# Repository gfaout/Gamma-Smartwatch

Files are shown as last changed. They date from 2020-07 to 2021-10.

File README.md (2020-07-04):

# Gamma-Smartwatch
Smartwatch designed in Summer of 2020

Version A (basic version):

Top Board Unfilled:

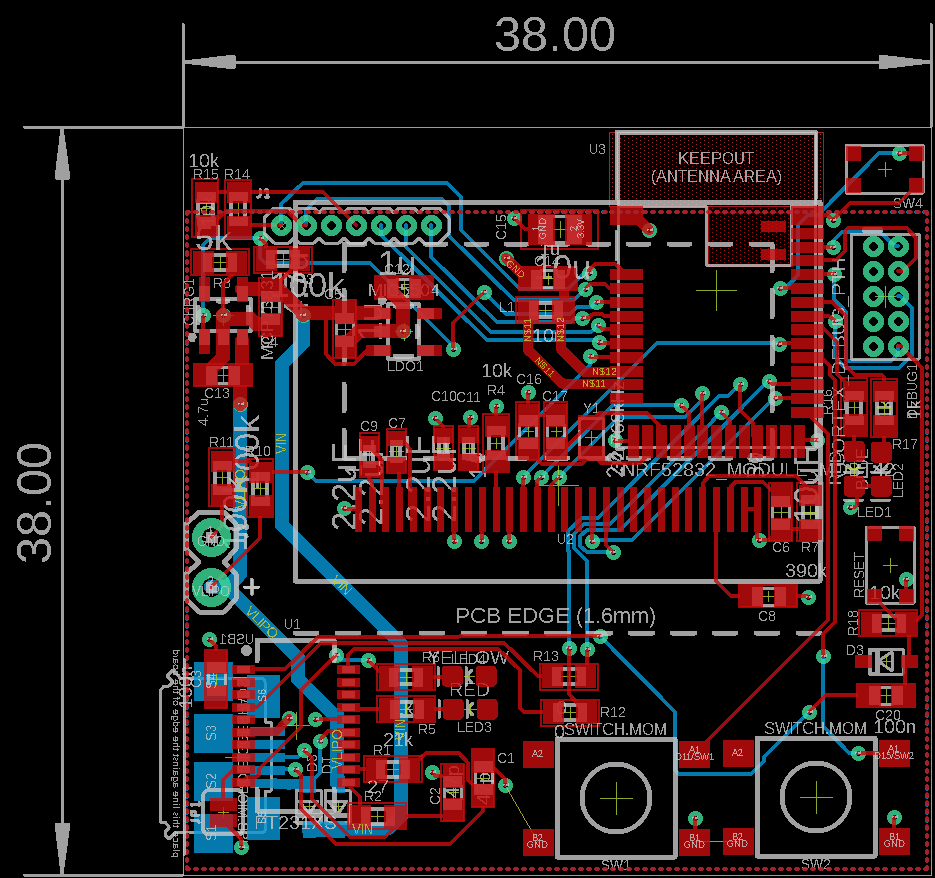
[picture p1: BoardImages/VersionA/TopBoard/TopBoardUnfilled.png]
The current unfilled top board


Top Board Filled:
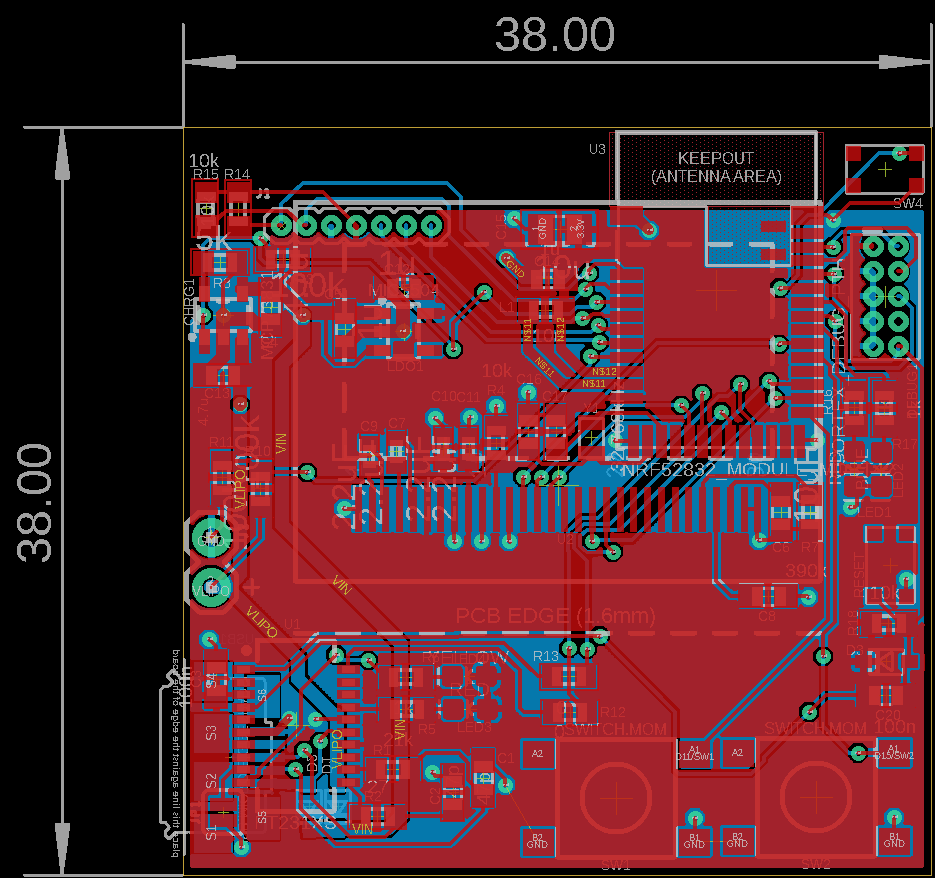
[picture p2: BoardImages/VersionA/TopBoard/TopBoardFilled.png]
The current filled top board


Bottom Board Unfilled:
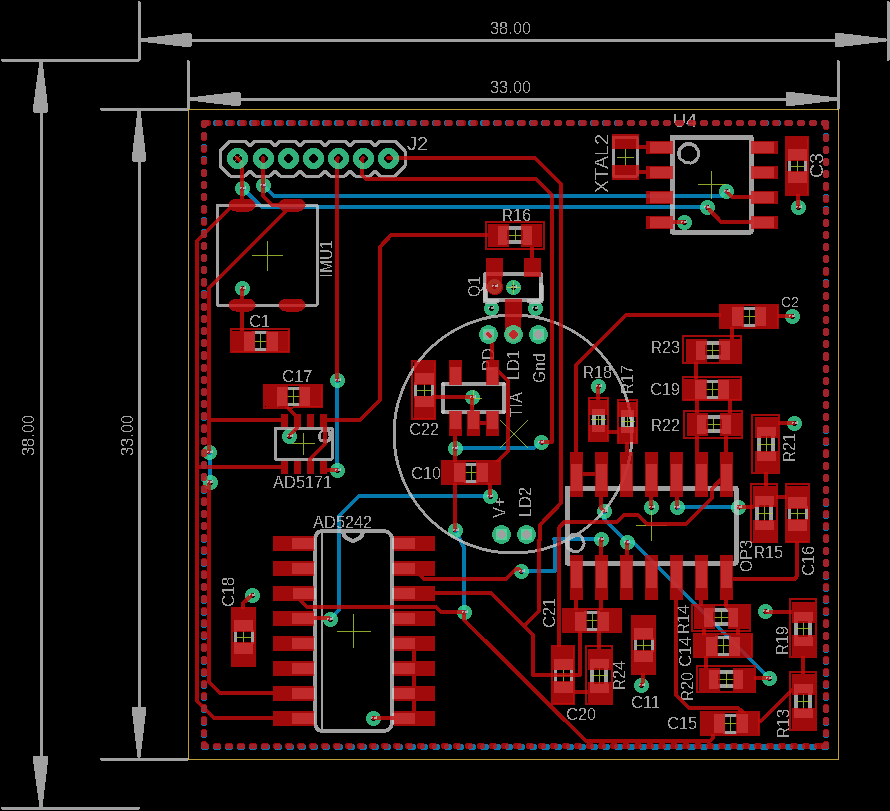
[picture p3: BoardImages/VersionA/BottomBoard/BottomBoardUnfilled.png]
The current unfilled bottom board


Bottom Board Filled:
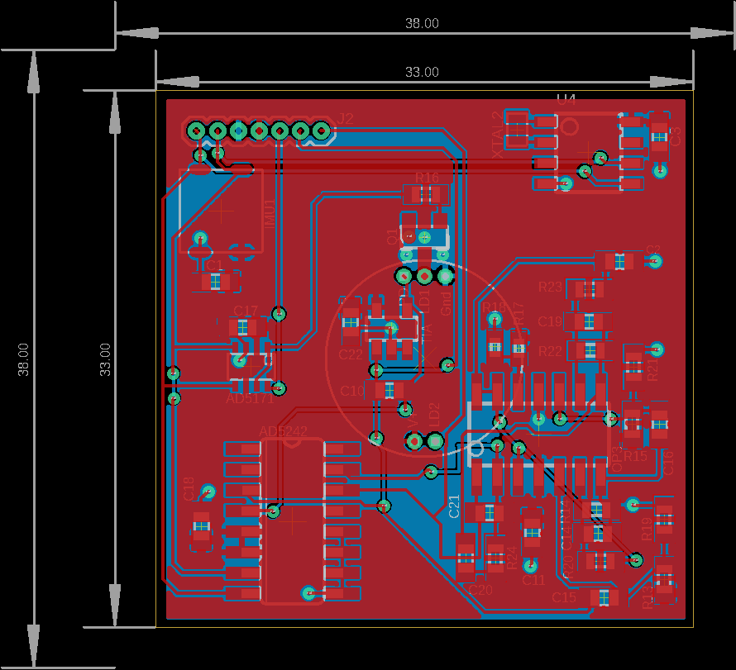
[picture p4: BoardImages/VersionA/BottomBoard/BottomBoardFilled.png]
The current filled bottom board


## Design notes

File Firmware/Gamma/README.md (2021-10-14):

This file is to lay out the general organization and initial testing of the Gamma Smartwatch firmware.

As of now, preliminary testing has been done on LCD displays, and i2c.  

Once parts are assembled (this will be done in the future), the full software testing and development will be completed.  

This is anticipated for Winter of 2022 and Spring of 2022 at the earliest.

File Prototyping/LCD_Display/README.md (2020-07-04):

# LCD Display (with Infrared Remote Control)

The code found in this folder was originally designed as my final project for the Arduino Milestone course.  
The link to the demonstration can be found [here](https://drive.google.com/file/d/1iYifw_N6cBzFy7ehYIgN_gkr_hAF68pH/view?usp=sharing)

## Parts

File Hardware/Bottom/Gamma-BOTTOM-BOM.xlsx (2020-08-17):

Gamma Smartwatch Bottom Board -- Revision A / Gautam Fotedar |  |  |  |  |  |  |  |  |  |  | Total | $0.00 | Total (in Bulk) | $0.00
BOM # | Comment | Designator | Description | Mounting Type | Package | Manufacturer | Manufacturer Part Number | Supplier | Supplier Part Number | Price per unit | Quantity | Total | Per 100 | Total
1 | CONN_07-1.27MM | J2 |  |  |  |  |  |  |  |  | 1 | $0.00 |  | $0.00
2 | LSM6DS3_CAST | IMU1 |  |  |  |  |  |  |  |  | 1 | $0.00 |  | $0.00
3 | 100 nF Capacitor | C1,C2,C10,C17,C18,C22 |  |  |  |  |  |  |  |  | 6 | $0.00 |  | $0.00
4 | 1 uF Capacitor | C3 |  |  |  |  |  |  |  |  | 1 | $0.00 |  | $0.00
5 | CRYSTALECS-.327-12.5-12-C-TR (CRYSTAL) (32.7680kHz) | XTAL2 |  |  |  |  |  |  |  |  | 1 | $0.00 |  | $0.00
6 | PCF8523 | U4 |  |  |  |  |  |  |  |  | 1 | $0.00 |  | $0.00
7 | 0.05 spaced Header Pins | J2 | Connector Header Through Hole 50 position 0.050" (1.27mm) |  |  | Sullins Connector Solutions | GRPB501VWVN-RC |  | S9014E-50-ND |  | 1 | $0.00 |  | $0.00
8 | AD5171 | AD5172 |  |  |  |  |  |  |  |  | 1 | $0.00 |  | $0.00
9 | AD5242 | AD5243 |  |  |  |  |  |  |  |  | 1 | $0.00 |  | $0.00
10 | TIA | TIA |  |  |  |  |  |  |  |  | 1 | $0.00 |  | $0.00
11 | NPN-Generic | Q1 |  |  |  |  |  |  |  |  | 1 | $0.00 |  | $0.00
12 | Resistor (valueless) | R16 |  |  |  |  |  |  |  |  | 1 | $0.00 |  | $0.00
13 | 1M Resistor | R20,R23 |  |  |  |  |  |  |  |  | 2 | $0.00 |  | $0.00
14 | 2.2n Capacitor | C14,C19 |  |  |  |  |  |  |  |  | 2 | $0.00 |  | $0.00
15 | 10M Resistor | R14,R22 |  |  |  |  |  |  |  |  | 2 | $0.00 |  | $0.00
16 | 10k Resistor | R17,R18,R24 |  |  |  |  |  |  |  |  | 3 | $0.00 |  | $0.00
17 | 220k resistor | R13,R19,R21 |  |  |  |  |  |  |  |  | 3 | $0.00 |  | $0.00
18 | Op amp | OP3 |  |  |  |  |  |  |  |  | 1 | $0.00 |  | $0.00
19 | 22n capacitor | C21 |  |  |  |  |  |  |  |  | 1 | $0.00 |  | $0.00
20 | 22u capacitor | C20 |  |  |  |  |  |  |  |  | 1 | $0.00 |  | $0.00
21 | 2.2u capacitor | C15 |  |  |  |  |  |  |  |  | 1 | $0.00 |  | $0.00

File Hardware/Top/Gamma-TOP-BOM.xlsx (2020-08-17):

Gamma Smartwatch Top Board -- Revision A / Gautam Fotedar |  |  |  |  |  |  |  |  |  |  | Total | $0.00 | Total (in Bulk) | $0.00
BOM # | Comment | Designator | Description | Mounting Type | Package | Manufacturer | Manufacturer Part Number | Supplier | Supplier Part Number | Price per unit | Quantity | Total | Per 100 | Total
1 | 47 pF Capacitor | C1,C2 |  |  |  |  |  |  |  |  | 2 | $0.00 |  | $0.00
2 | 27 ohm resistor | R1,R2 |  |  |  |  |  |  |  |  | 2 | $0.00 |  | $0.00
3 | 100 nF Capacitor | C3, C19, C20 |  |  |  |  |  |  |  |  | 3 | $0.00 |  | $0.00
4 | FT231XS USB Serial | U1 |  |  |  |  |  |  |  |  | 1 | $0.00 |  | $0.00
5 | SMT-JUMPER_2_NO_SILK (Version 1) | JP1 |  |  |  |  |  |  |  |  | 1 | $0.00 |  | $0.00
6 | 1k Resistor | R5, R6, R16, R17 |  |  |  |  |  |  |  |  | 4 | $0.00 |  | $0.00
7 | Red LED | LED1, LED3 |  |  |  |  |  |  |  |  | 2 | $0.00 |  | $0.00
8 | Yellow LED | LED4 |  |  |  |  |  |  |  |  | 1 | $0.00 |  | $0.00
9 | 0 ohm resistor (not sure if needed) | R12, R13 |  |  |  |  |  |  |  |  | 2 | $0.00 |  | $0.00
10 | CONN_07-1.27MM (CONN_07) | J1 |  |  |  |  |  |  |  |  | 1 | $0.00 |  | $0.00
11 | OLED UG-2864HSWEG01 | U2 |  |  |  |  |  |  |  |  | 1 | $0.00 |  | $0.00
12 | 2.2 uF 0402 Capacitor | C7, C9, C10, C11 |  |  |  |  |  |  |  |  | 4 | $0.00 |  | $0.00
13 | 10k resistor | R4, R14, R15, R18 |  |  |  |  |  |  |  |  | 4 | $0.00 |  | $0.00
14 | 390k resistor | R7 |  |  |  |  |  |  |  |  | 1 | $0.00 |  | $0.00
15 | 2.2 uF 0603 Capacitor | C8 |  |  |  |  |  |  |  |  | 1 | $0.00 |  | $0.00
16 | 10 uF 0603 Capacitor | C6, C15 |  |  |  |  |  |  |  |  | 2 | $0.00 |  | $0.00
17 | CONN_02 for Power Management | J2 |  |  |  |  |  |  |  |  | 1 | $0.00 |  | $0.00
18 | Schottky Diode | D1,D2, D3 |  |  |  |  |  |  |  |  | 3 | $0.00 |  | $0.00
19 | 1 uF 0603 capacitor | C5,C12, C14 |  |  |  |  |  |  |  |  | 3 | $0.00 |  | $0.00
20 | MIC5504 Voltage Regulator | LDO1 |  |  |  |  |  |  |  |  | 1 | $0.00 |  | $0.00
21 | 4.7 uF Capacitor | C4, C13 |  |  |  |  |  |  |  |  | 2 | $0.00 |  | $0.00
22 | 100K Resistor | R3, R10, R11 |  |  |  |  |  |  |  |  | 3 | $0.00 |  | $0.00
23 | MCP73831 T Li-Ion, Li-Pol Controller | CHRG1 |  |  |  |  |  |  |  |  | 1 | $0.00 |  | $0.00
24 | 5k resistor | R8 |  |  |  |  |  |  |  |  | 1 | $0.00 |  | $0.00
25 | FT24C64A EEPROM | U5 |  |  |  |  |  |  |  |  | 1 | $0.00 |  | $0.00
26 | 120 pF Capacitor | C18, C21 |  |  |  |  |  |  |  |  | 2 | $0.00 |  | $0.00
27 | 2.1 uH NFC Antenna | NFCANTENNA |  |  |  | Molex | 1462360151 |  |  |  | 1 | $0.00 |  | $0.00
28 | SPST-PTS830GG140 | RESET |  |  |  |  |  |  |  |  | 1 | $0.00 |  | $0.00
29 | Cortex Debug Connector - 10 pin | DEBUG1 |  |  |  |  |  |  |  |  | 1 | $0.00 |  | $0.00
30 | SWITCH.MOM (TACTILE_SWITCH_SMD_6.2MM_TALL) | SW1, SW2 |  |  |  |  |  |  |  |  | 2 | $0.00 |  | $0.00
31 | DFU SPST-PTS830GG140 | SW4 |  |  |  |  |  |  |  |  | 1 | $0.00 |  | $0.00
32 | 10 uH Inductor | L1 |  |  |  |  |  |  |  |  | 1 | $0.00 |  | $0.00
33 | Valuelesss capacitors | C16, C17 |  |  |  |  |  |  |  |  | 2 | $0.00 |  | $0.00
34 | CRYSTALECS-.327-12.5-12-C-TR (CRYSTAL) (32.768kHz) | Y1 |  |  |  |  |  |  |  |  | 1 | $0.00 |  | $0.00
35 | Blue LED | LED2 |  |  |  |  |  |  |  |  | 1 | $0.00 |  | $0.00
36 | NRF52832_MODULE_MDBT42 | U3 |  |  |  |  |  |  |  |  | 1 | $0.00 |  | $0.00

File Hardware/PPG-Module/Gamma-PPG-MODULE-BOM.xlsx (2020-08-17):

Design Name -- Revision Code / Designer |  |  |  |  |  |  |  |  |  |  | Total | $4.73 | Total (in Bulk) | $3.24
BOM # | Comment | Designator | Description | Mounting Type | Package | Manufacturer | Manufacturer Part Number | Supplier | Supplier Part Number | Price per unit | Quantity | Total | Per 100 | Total
1 | Photodiode | PD | Photodiode 940nm 100ns 130° 2-SMD, Gull Wing | SMD | 2-SMD, Gull Wing | Vishay Semiconductor Opto Division | VBPW34S | Digi-Key | 751-1500-1-ND | $1.13 | 1 | $1.13 | $0.57 | $0.57
2 | 2.2uF capacitor | C1 | 2.2µF ±10% 25V Ceramic Capacitor X5R 0603 (1608 Metric) | SMD | 0603 | Samsung Electro-Mechanics | CL10A105KA8NNNC | Digi-Key | 1276-1102-1-ND | $0.10 | 1 | $0.10 | $0.02 | $0.02
3 | Green LED | LED1 | Green 525nm LED Indication - Discrete 3.1V 0805 (2012 Metric) | SMD | 0805 | QT Brightek (QTB) | QBLP631-IG | Digi-Key | 1516-1084-1-ND | $0.39 | 1 | $0.39 | $0.16 | $0.16
4 | 0.05 spaced Header Pins | J1 | Connector Header Through Hole 50 position 0.050" (1.27mm) | THT | N/A | Sullins Connector Solutions | GRPB501VWVN-RC | Digi-Key | S9014E-50-ND | $3.11 | 1 | $3.11 | $2.49 | $2.49

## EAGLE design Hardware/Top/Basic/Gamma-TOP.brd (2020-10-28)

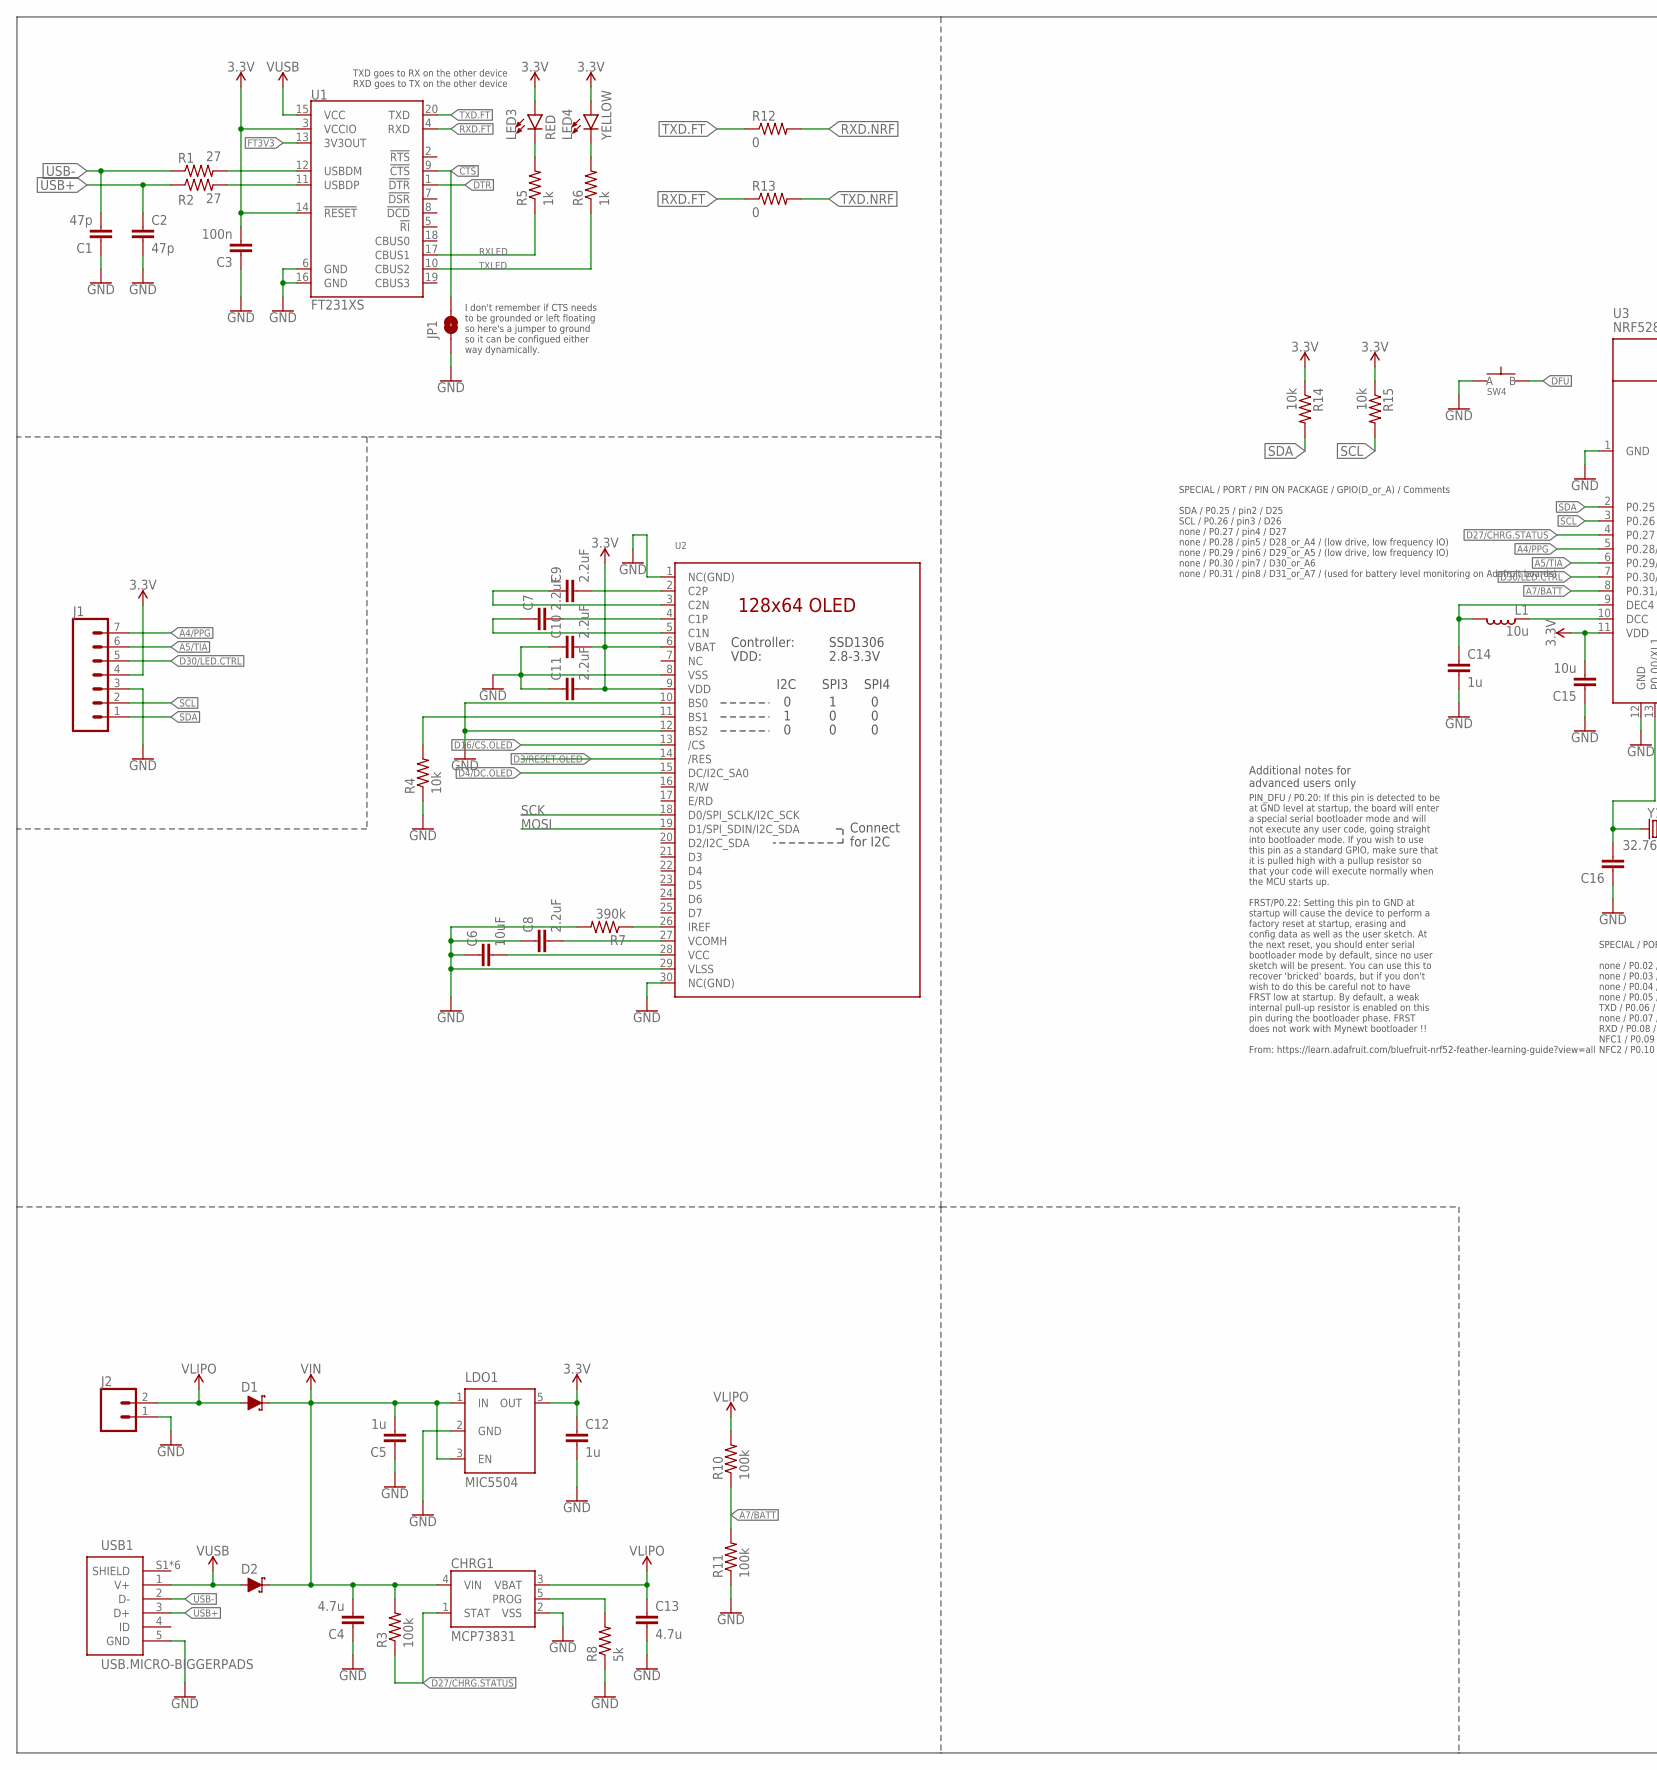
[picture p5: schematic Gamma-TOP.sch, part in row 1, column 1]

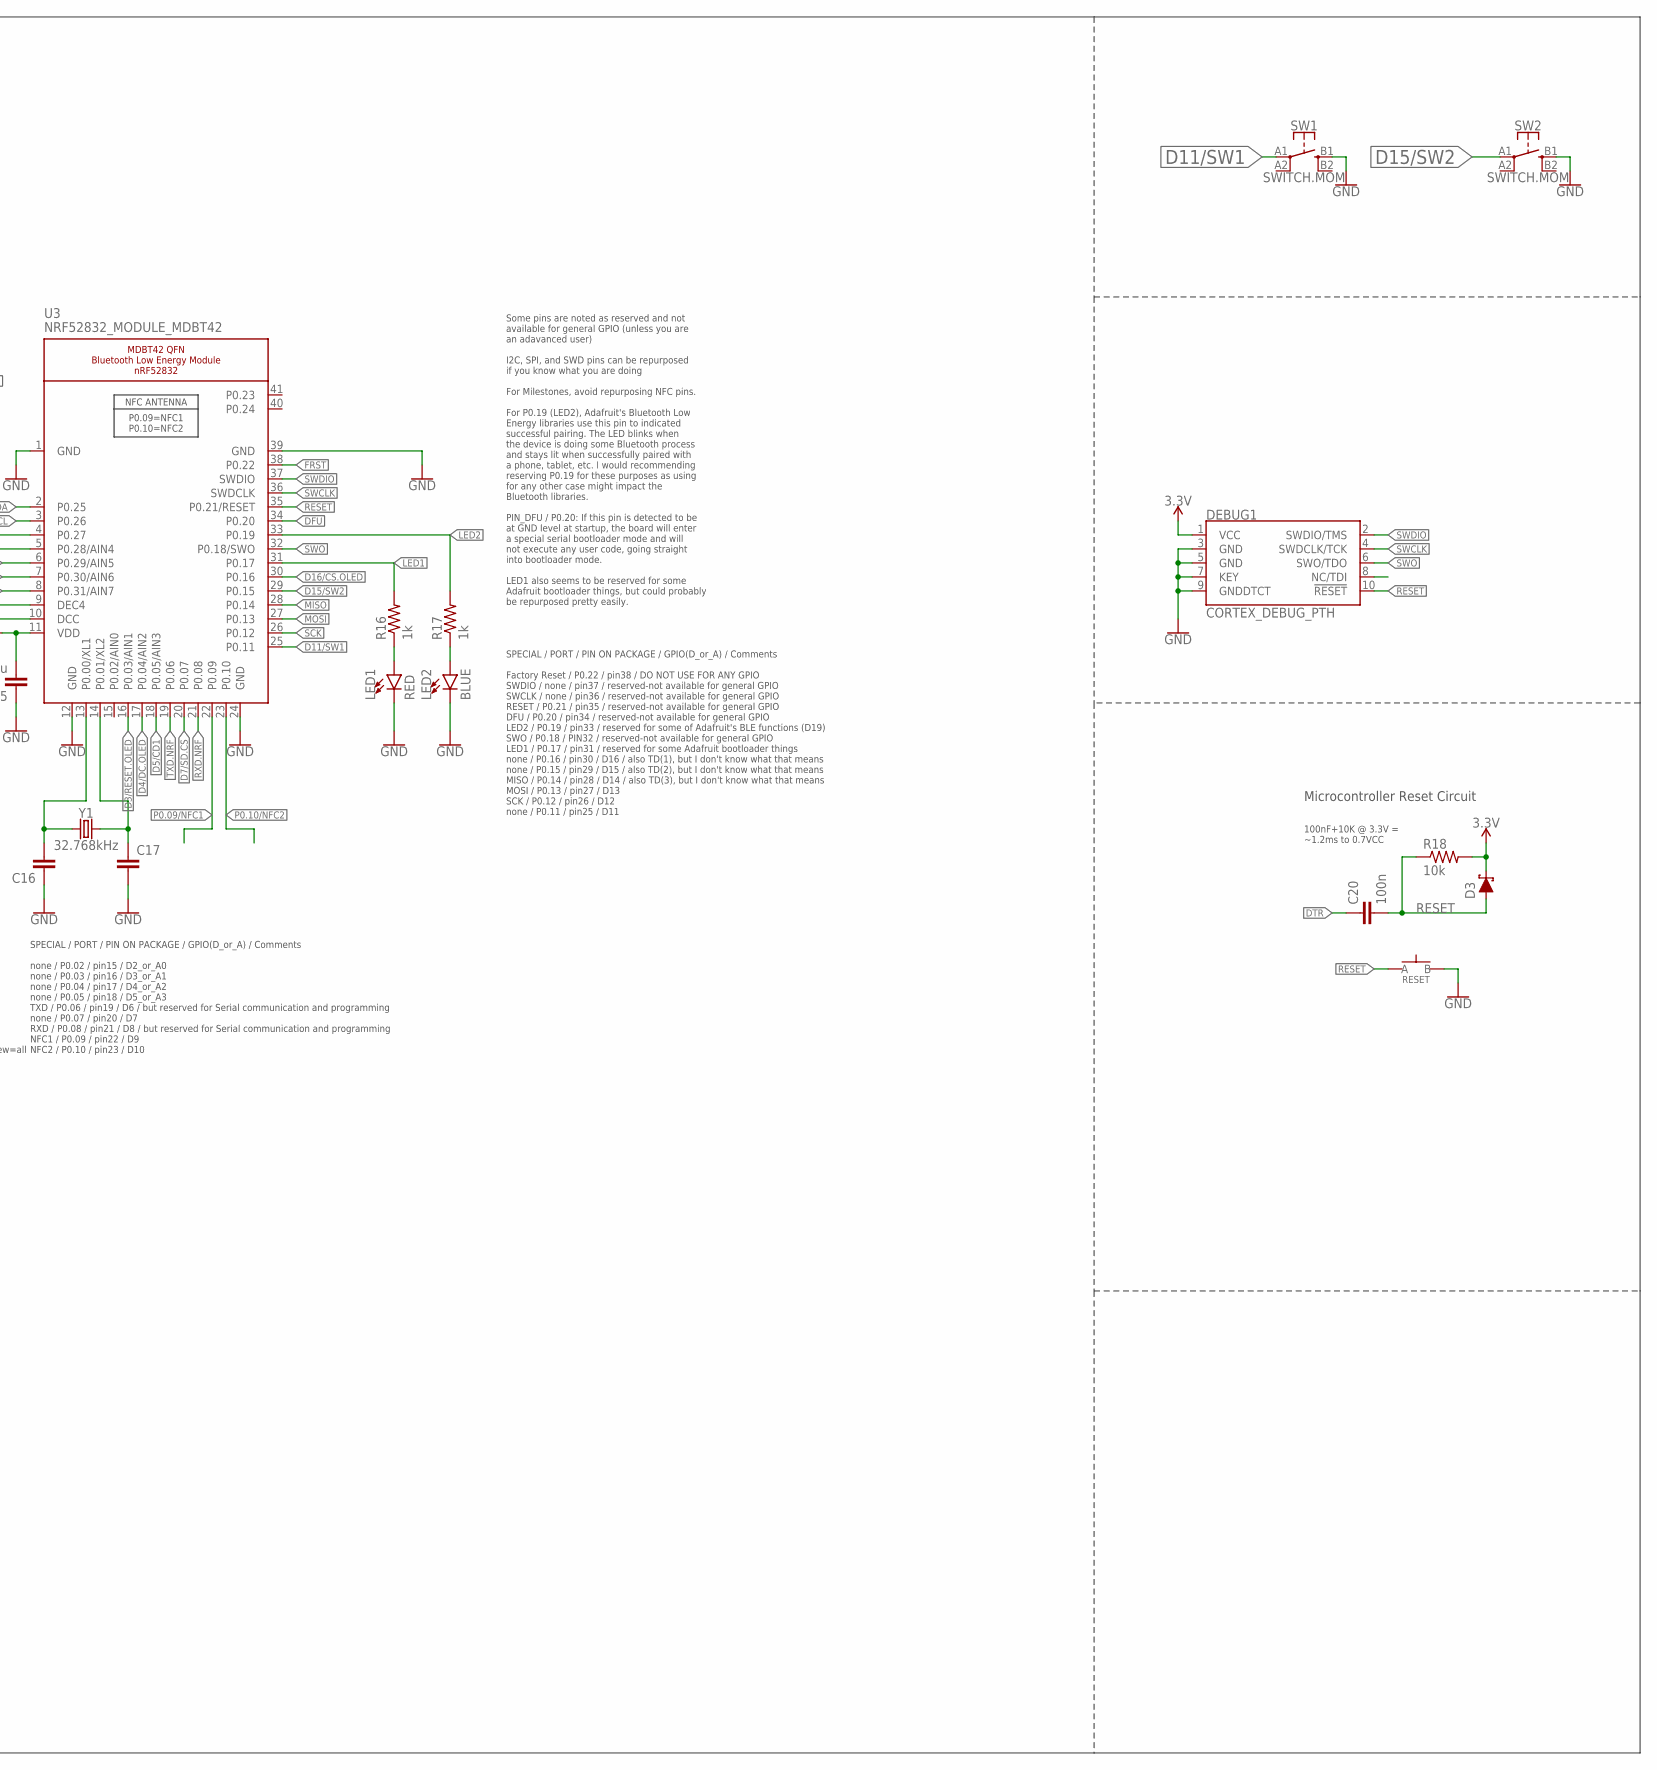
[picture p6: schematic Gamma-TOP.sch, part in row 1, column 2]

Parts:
C1, C2: 47p; C0603
C3, C20: 100n; C0603
C4, C13: 4.7u; C0603
C5, C12, C14: 1u; C0603
C6: 10uF; C0603
C7, C9, C10, C11: 2.2uF; C0402
C8: 2.2uF; C0603
C15: 10u; C0805
C16, C17: CAPACITOR0603; C0603
CHRG1: MCP73831; SOT23-5
D1, D2, D3: SCHOTTKY-USC; USC
DEBUG1: CORTEX_DEBUG_PTH; 2X5-PTH-1.27MM
J1: CONN_07-1.27MM; 1X07_1.27MM
J2: CONN_02; 1X02
JP1: JUMPER-SMT_2_NO_SILK; SMT-JUMPER_2_NO_SILK
L1: 10u; L0603
LDO1: MIC5504; SOT23-5
LED1, LED3: RED; LED-0603
LED2: BLUE; LED-0603
LED4: YELLOW; LED-0603
R1, R2: 27; R0603
R3, R10, R11: 100k; R0603
R4, R14, R15, R18: 10k; R0603
R5, R6, R16, R17: 1k; R0603
R7: 390k; R0603
R8: 5k; R0603
R12, R13: 0; R0603
RESET: SPST-PTS830GG140-COPY.1-3; BUTTON-GULLWING
SW1, SW2: SWITCH.MOM; TACTILE_SWITCH_SMD_6.2MM_TALL
SW4: SPST-PTS830GG140-COPY.1-3; BUTTON-GULLWING
U1: FT231XS; SSOP20_L
U2: DISP_OLED_UG-2864HSWEG01-NO-WRAPAROUND; UG-2864HSWEG01_0.96IN_NO-WRAPAROUND
U3: NRF52832_MODULE_MDBT42; BLE_MODULE_RAYTAC_MDBT42
USB1: USB.MICRO-BIGGERPADS; USB-MICRO-01.BIGGERPADS
Y1: 32.768kHz; 2-SMD.NOLEAD.2.0MMTO1.2MM

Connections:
3.3V: C3.2, C10.2, C11.2, C12.1, C15.2, D3.- (C), DEBUG1.1 (VCC), J1.4, LDO1.5 (OUT), LED3.A, LED4.A, R14.1, R15.1, R18.2, U1.3 (VCCIO), U1.14 (!RESET), U2.6 (VBAT), U2.9 (VDD), U3.11 (VDD)
!CTS: JP1.2, U1.9 (!CTS)
A4/PPG: J1.7, U3.5 (P0.28/AIN4)
A5/TIA: J1.6, U3.6 (P0.29/AIN5)
A7/BATT: R10.1, R11.2, U3.8 (P0.31/AIN7)
D3/RESET.OLED: U2.14 (/RES), U3.16 (P0.03/AIN1)
D4/DC.OLED: U2.15 (DC/I2C_SA0), U3.17 (P0.04/AIN2)
D5/CD1: U3.18 (P0.05/AIN3)
D7/SD.CS: U3.20 (P0.07)
D11/SW1: SW1.A1 (1), U3.25 (P0.11)
D15/SW2: SW2.A1 (1), U3.29 (P0.15)
D16/CS.OLED: U2.13 (/CS), U3.30 (P0.16)
D27/CHRG.STATUS: CHRG1.1 (STAT), R3.1, U3.4 (P0.27)
D30/LED.CTRL: J1.5, U3.7 (P0.30/AIN6)
DFU: SW4.3 (B), U3.34 (P0.20)
DTR: C20.1, U1.1 (!DTR)
FRST: U3.38 (P0.22)
FT3V3: U1.13 (3V3OUT)
GND: C1.1, C2.2, C3.1, C4.1, C5.1, C6.1, C8.1, C10.1, C11.1, C12.2, C13.2, C14.2, C15.1, C16.1, C17.2, CHRG1.2 (VSS), DEBUG1.3 (GND), DEBUG1.5 (GND), DEBUG1.7 (KEY), DEBUG1.9 (GNDDTCT), J1.3, J2.1, JP1.1, LDO1.2 (GND), LED1.C, LED2.C, R4.1, R7.2, R8.1, R11.1, RESET.3 (B), SW1.B1 (3), SW2.B1 (3), SW4.1 (A), U1.6 (GND), U1.16 (GND), U2.1 (NC(GND)), U2.8 (VSS), U2.10 (BS0), U2.12 (BS2), U2.29 (VLSS), U2.30 (NC(GND)), U3.1 (GND), U3.12 (GND), U3.24 (GND), U3.39 (GND), USB1.5 (GND)
LED1: R16.2, U3.31 (P0.17)
LED2: R17.2, U3.33 (P0.19)
MISO: U3.28 (P0.14)
MOSI: U2.19 (D1/SPI_SDIN/I2C_SDA), U3.27 (P0.13)
unnamed: R4.2, U2.11 (BS1)
unnamed: R7.1, U2.26 (IREF)
unnamed: C9.2, U2.2 (C2P)
unnamed: C16.2, U3.13 (P0.00/XL1), Y1.P$1 (1)
unnamed: C9.1, U2.3 (C2N)
unnamed: C17.1, U3.14 (P0.01/XL2), Y1.P$2 (2)
unnamed: C7.2, U2.4 (C1P)
unnamed: C7.1, U2.5 (C1N)
unnamed: LED1.A, R16.1
unnamed: LED2.A, R17.1
unnamed: L1.1, U3.10 (DCC)
unnamed: C14.1, L1.2, U3.9 (DEC4)
unnamed: C6.2, U2.28 (VCC)
unnamed: C8.2, U2.27 (VCOMH)
unnamed: CHRG1.5 (PROG), R8.2
unnamed: R1.2, U1.12 (USBDM)
unnamed: R2.2, U1.11 (USBDP)
unnamed: LED3.C, R5.2
unnamed: LED4.C, R6.2
P0.09/NFC1: U3.22 (P0.09)
P0.10/NFC2: U3.23 (P0.10)
RESET: C20.2, D3.+ (A), DEBUG1.10 (!RESET), R18.1, RESET.1 (A), U3.35 (P0.21/RESET)
RXD.FT: R13.1, U1.4 (RXD)
RXD.NRF: R12.2, U3.21 (P0.08)
RXLED: R5.1, U1.17 (CBUS1)
SCK: U2.18 (D0/SPI_SCLK/I2C_SCK), U3.26 (P0.12)
SCL: J1.2, R15.2, U3.3 (P0.26)
SDA: J1.1, R14.2, U3.2 (P0.25)
SWCLK: DEBUG1.4 (SWDCLK/TCK), U3.36 (SWDCLK)
SWDIO: DEBUG1.2 (SWDIO/TMS), U3.37 (SWDIO)
SWO: DEBUG1.6 (SWO/TDO), U3.32 (P0.18/SWO)
TXD.FT: R12.1, U1.20 (TXD)
TXD.NRF: R13.2, U3.19 (P0.06)
TXLED: R6.1, U1.10 (CBUS2)
USB+: C2.1, R2.1, USB1.3 (D+)
USB-: C1.2, R1.1, USB1.2 (D-)
VIN: C4.2, C5.2, CHRG1.4 (VIN), D1.- (C), D2.- (C), LDO1.1 (IN), LDO1.3 (EN), R3.2
VLIPO: C13.1, CHRG1.3 (VBAT), D1.+ (A), J2.2, R10.2
V_USB: D2.+ (A), U1.15 (VCC), USB1.1 (V+)

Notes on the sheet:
Microcontroller Reset Circuit
100nF+10K @ 3.3V = ~1.2ms to 0.7VCC
SPECIAL / PORT / PIN ON PACKAGE / GPIO(D_or_A) / Comments SDA / P0.25 / pin2 / D25 SCL / P0.26 / pin3 / D26 none / P0.27 / pin4 / D27 none / P0.28 / pin5 / D28_or_A4 / (low drive, low frequency IO) none / P0.29 / pin6 / D29_or_A5 / (low drive, low frequency IO) none / P0.30 / pin7 / D30_or_A6 none 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
SPECIAL / PORT / PIN ON PACKAGE / GPIO(D_or_A) / Comments none / P0.02 / pin15 / D2_or_A0 none / P0.03 / pin16 / D3_or_A1 none / P0.04 / pin17 / D4_or_A2 none / P0.05 / pin18 / D5_or_A3 TXD / P0.06 / pin19 / D6 / but reserved for Serial communication and programming none / P0.07 / pin20 / D7 RXD / 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
SPECIAL / PORT / PIN ON PACKAGE / GPIO(D_or_A) / Comments Factory Reset / P0.22 / pin38 / DO NOT USE FOR ANY GPIO SWDIO / none / pin37 / reserved-not available for general GPIO SWCLK / none / pin36 / reserved-not available for general GPIO RESET / P0.21 / pin35 / reserved-not available for general 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
Some pins are noted as reserved and not available for general GPIO (unless you are an adavanced user) I2C, SPI, and SWD pins can be repurposed if you know what you are doing For Milestones, avoid repurposing NFC pins. For P0.19 (LED2), Adafruit's Bluetooth Low Energy libraries use this pin to indic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
PIN_DFU / P0.20: If this pin is detected to be at GND level at startup, the board will enter a special serial bootloader mode and will not execute any user code, going straight into bootloader mode. If you wish to use this pin as a standard GPIO, make sure that it is pulled high with a pullup resis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
Additional notes for advanced users only
TXD goes to RX on the other device RXD goes to TX on the other device
I don't remember if CTS needs to be grounded or left floating so here's a jumper to ground so it can be configued either way dynamically.

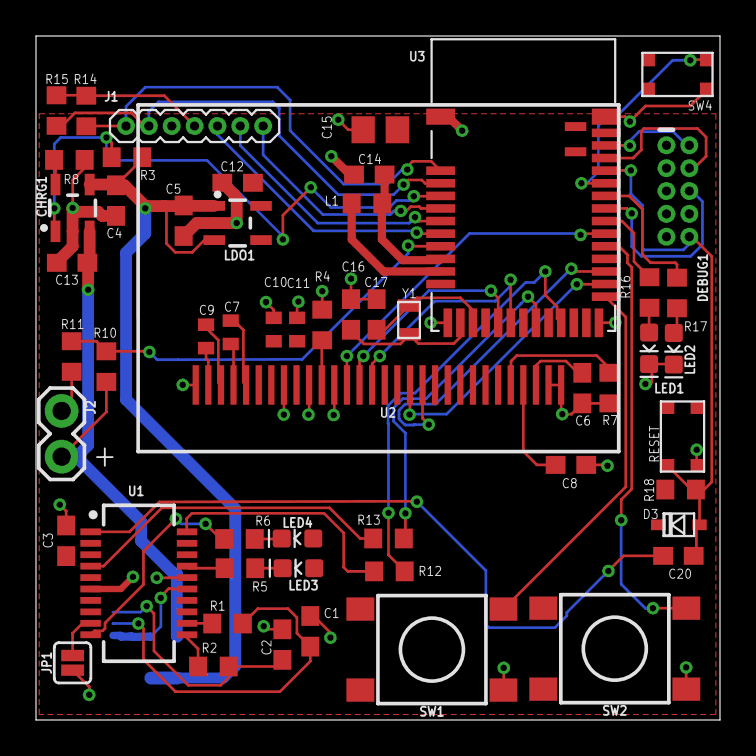
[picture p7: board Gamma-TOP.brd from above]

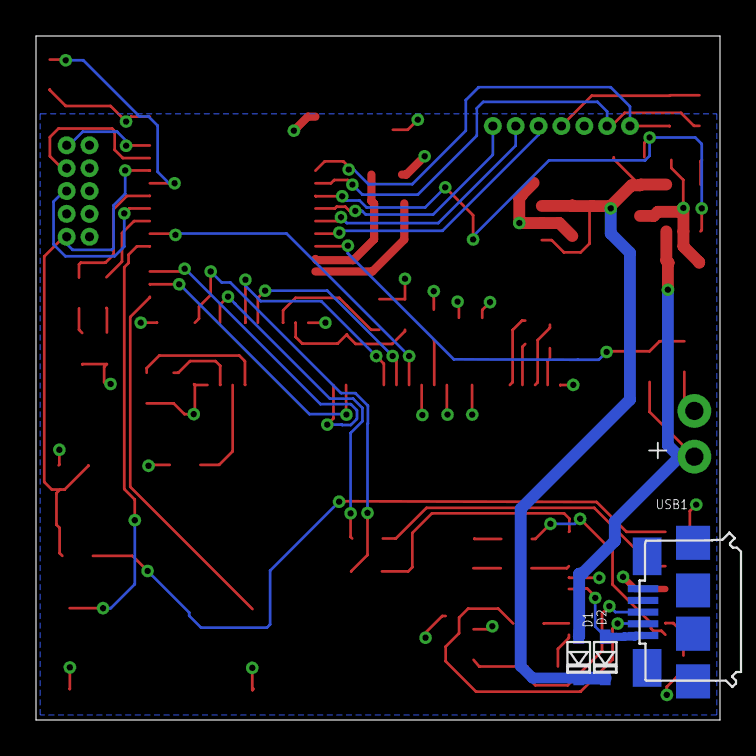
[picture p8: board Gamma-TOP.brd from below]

Board: 2 copper layers, 38.0 x 38.0 mm, 58 parts (3 on the bottom side), 55 nets.

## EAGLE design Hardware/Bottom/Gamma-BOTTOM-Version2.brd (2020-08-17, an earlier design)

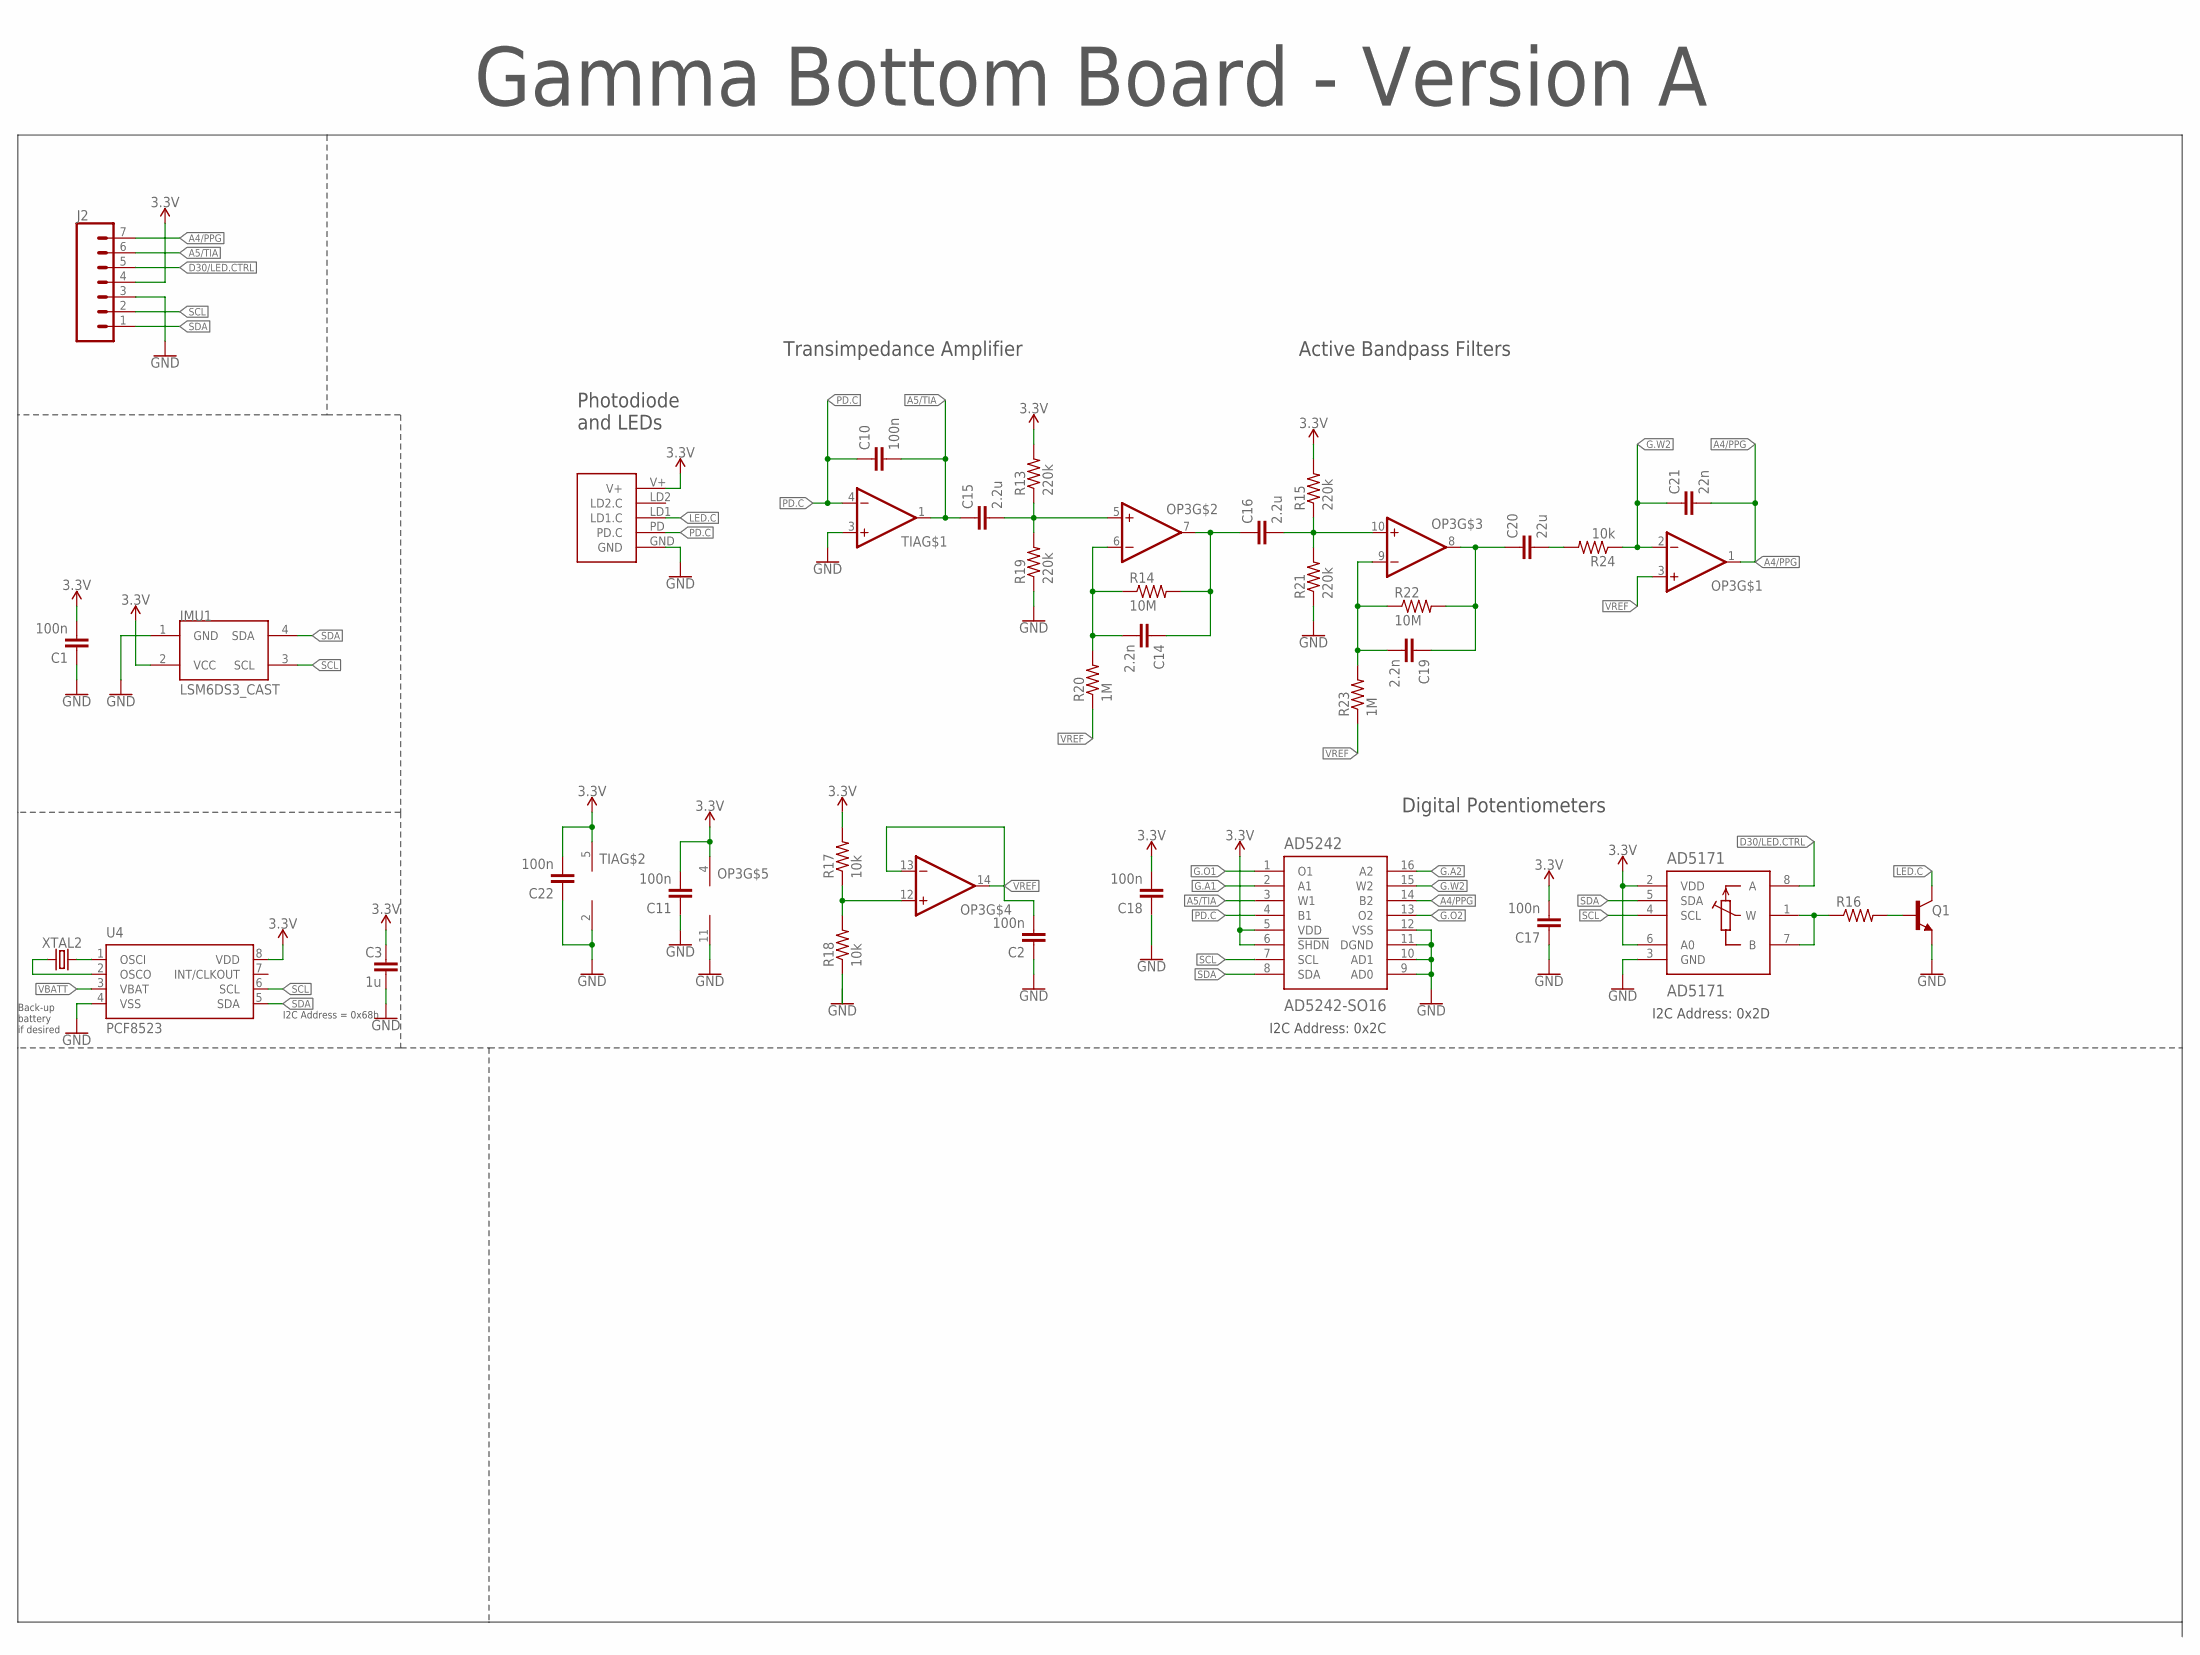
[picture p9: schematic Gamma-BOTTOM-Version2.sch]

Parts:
AD5171: AD5171; SOT-23-8
AD5242: AD5242-SO16; SO16
C1, C2, C10, C11, C17, C18, C22: 100n; C0603
C3: 1u; C0603
C14, C19: 2.2n; C0603
C15, C16: 2.2u; C0603
C20: 22u; C0603
C21: 22n; C0603
IMU1: LSM6DS3_CAST
J2: CONN_07-1.27MM; 1X07_1.27MM
OP3: OP-QUAD-SO14; SO14
Q1: NPN-GENERIC; SOT23-3
R13, R15, R19, R21: 220k; R0603
R14, R22: 10M; R0603
R16: RESISTOR0603; R0603
R17, R18: 10k; R0402
R20, R23: 1M; R0603
R24: 10k; R0603
TIA: OP-SINGLEOT; SOT23-5
U4: PCF8523; SO8; DIGIKEY 568-5306-1-ND
U$3: PPG.MODULE.2
XTAL2: 32.7680kHz; 2-SMD.NOLEAD.2.0MMTO1.2MM

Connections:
3.3V: AD5171.2 (VDD), AD5171.6 (A0), AD5242.5 (VDD), AD5242.6 (!SHDN), C1.2, C3.1, C11.2, C17.2, C18.2, C22.2, IMU1.2 (VCC), J2.4, OP3.4 (V+), R13.2, R15.2, R17.2, TIA.5 (V+), U4.8 (VDD), U$3.V+
A4/PPG: AD5242.14 (B2), C21.2, J2.7, OP3.1 (OUT)
A5/TIA: AD5242.3 (W1), C10.2, C15.1, J2.6, TIA.1 (OUT)
D30/LED.CTRL: AD5171.8 (A), J2.5
G.A1: AD5242.2 (A1)
G.A2: AD5242.16 (A2)
G.O1: AD5242.1 (O1)
G.O2: AD5242.13 (O2)
G.W2: AD5242.15 (W2), C21.1, OP3.2 (-IN), R24.1
GND: AD5171.3 (GND), AD5242.9 (AD0), AD5242.10 (AD1), AD5242.11 (DGND), AD5242.12 (VSS), C1.1, C2.1, C3.2, C11.1, C17.1, C18.1, C22.1, IMU1.1 (GND), J2.3, OP3.11 (V-), Q1.2 (E), R18.1, R19.1, R21.1, TIA.2 (V-), TIA.3 (+IN), U4.4 (VSS), U$3.GND
LED.C: Q1.3 (C), U$3.LD1 (LD1.C)
unnamed: U4.2 (OSCO), XTAL2.P$1 (1)
unnamed: U4.1 (OSCI), XTAL2.P$2 (2)
unnamed: Q1.1 (B), R16.2
unnamed: AD5171.1 (W), AD5171.7 (B), R16.1
unnamed: OP3.12 (+IN), R17.1, R18.2
unnamed: C15.2, OP3.5 (+IN), R13.1, R19.2
unnamed: C14.2, OP3.6 (-IN), R14.1, R20.2
unnamed: C14.1, C16.1, OP3.7 (OUT), R14.2
unnamed: C16.2, OP3.10 (+IN), R15.1, R21.2
unnamed: C19.2, OP3.9 (-IN), R22.1, R23.2
unnamed: C19.1, C20.1, OP3.8 (OUT), R22.2
unnamed: C20.2, R24.2
PD.C: AD5242.4 (B1), C10.1, TIA.4 (-IN), U$3.PD (PD.C)
SCL: AD5171.4 (SCL), AD5242.7 (SCL), IMU1.3 (SCL), J2.2, U4.6 (SCL)
SDA: AD5171.5 (SDA), AD5242.8 (SDA), IMU1.4 (SDA), J2.1, U4.5 (SDA)
VBATT: U4.3 (VBAT)
VREF: C2.2, OP3.3 (+IN), OP3.13 (-IN), OP3.14 (OUT), R20.1, R23.1

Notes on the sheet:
Photodiode and LEDs
Active Bandpass Filters
Digital Potentiometers
Transimpedance Amplifier
I2C Address: 0x2C
I2C Address: 0x2D
Gamma Bottom Board - Version A
I2C Address = 0x68h
Back-up battery if desired

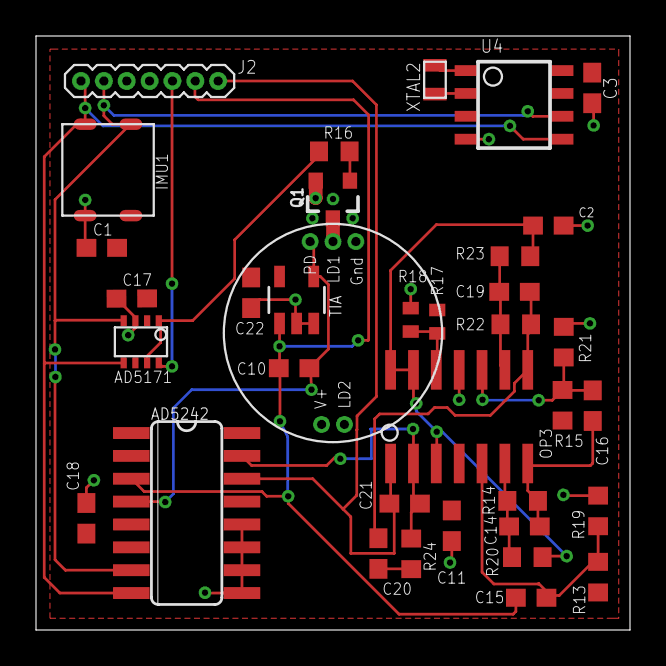
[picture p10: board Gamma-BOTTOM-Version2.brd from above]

Board: 2 copper layers, 33.0 x 33.0 mm, 36 parts (0 on the bottom side), 23 nets.

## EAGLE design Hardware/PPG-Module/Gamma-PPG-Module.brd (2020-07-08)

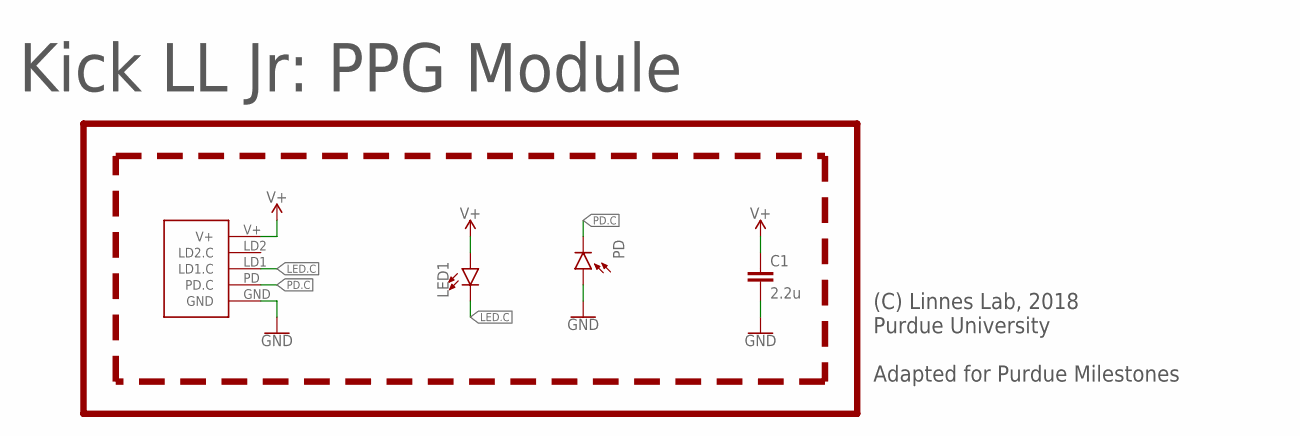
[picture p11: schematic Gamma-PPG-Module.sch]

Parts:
C1: 2.2u; C0603
J1: PPG.MODULE.2
LED1: LED0805; LED-0805
PD: PHOTODIODE.-SMD.GULLWING; 2-SMD.GULLWING
U$3: LINNES.LAB.LOGO

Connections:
GND: C1.2, J1.GND, PD.+ (A)
LED.C: J1.LD1 (LD1.C), LED1.C
PD.C: J1.PD (PD.C), PD.- (C)
V+: C1.1, J1.V+, LED1.A

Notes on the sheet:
Kick LL Jr: PPG Module
(C) Linnes Lab, 2018 Purdue University Adapted for Purdue Milestones

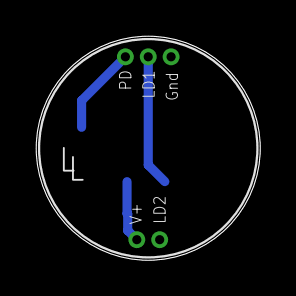
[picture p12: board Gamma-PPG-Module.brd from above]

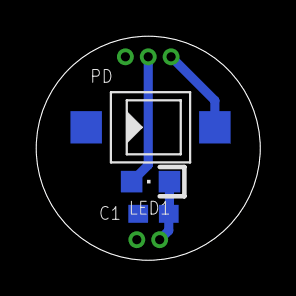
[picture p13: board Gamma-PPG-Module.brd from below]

Board: 2 copper layers, 12.4 x 12.4 mm, 5 parts (3 on the bottom side), 4 nets.

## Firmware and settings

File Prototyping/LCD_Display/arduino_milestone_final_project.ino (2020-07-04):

#include <IRremote.h>  //including infrared remote header file     
#include <LiquidCrystal.h>
int RECV_PIN = 7; // the pin where you connect the output pin of IR sensor     
IRrecv irrecv(RECV_PIN);     
decode_results results;     
int on_state = 0;
LiquidCrystal lcd(12, 11, 5, 4, 3, 2);


char thank_you[11] = "Thank you ";
char very_much[11] = "very much ";
char for_teaching[14] = "for teaching ";
char this_course[13] = "this course.";

char* words[4] = {thank_you, very_much, for_teaching, this_course};
int word_idx = 0;
void setup()     
{     
Serial.begin(9600);     
irrecv.enableIRIn();
lcd.begin(16,2);     
on_state = 1;
word_idx = -1;
lcd.display();
}
void loop()     
{     
if (irrecv.decode(&results))// Returns 0 if no data ready, 1 if data ready.     
{     
 int value = results.value;// Results of decoding are stored in result.value     
 if (value == -28561) {
    word_idx++;
    lcd.setCursor(0,1);
    lcd.print(words[word_idx]);
 }
 else if (value == -8161) {
  word_idx--;
  lcd.setCursor(0,1);
  lcd.print(words[word_idx]);
 }
 else if (value == -23971) {
    if (on_state == 1) {
      lcd.noDisplay();
      on_state--;
    }
    else {
      lcd.display();
      on_state = 1;
    }
 }

 delay(250);
 irrecv.resume(); // Restart the ISR state machine and Receive the next value     
}
}     

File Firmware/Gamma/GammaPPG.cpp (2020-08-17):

// Note:  Most of this code was taken from the KickJrPPG repository
// From the author listed below.

/*
 FILENAME:      GammaPPG.cpp
 AUTHOR:        Orlando S. Hoilett
 EMAIL:         ohoilett@purdue.edu / orlandohoilett@gmail.com
 VERSION:    1.0.0
 
 
 ABBREVIATIONS
 
 PPG - Photoplethysmography - Process of measuring changes in volume in light.
  Used to measure heart rate, respiration, and blood oxygen by measuring
  changes in volume in the blood vessels.
 
 BPF - Bandpass filters
 
 I2C
 
 
 DESCRIPTION
 
 
 A FEW RESOURCES:
 
 Analog-to-Digital Conversion
 https://www.instructables.com/id/Analog-to-Digital-Conversion-Tutorial/
 
 I2C
 
 Digital Potentiometers
 
 
 UPDATES
 
 
 */


#include "GammaPPG.h"

const uint8_t ledPin = 30;
const uint8_t ppgPin = A4;
const uint8_t tiaPin = A5;
const uint8_t ad5171_address = 0x2D;
const uint8_t ad5242_address = 0x2C;

//DEFAULT CONSTRUCTOR
//Must be called before setup in .ino code
GammaPPG::GammaPPG()
{
}

//void GammaPPG::begin()
//
//Initializes functions, member variables, and member objects of the PPG class
//Must be called before setup in .ino code
void GammaPPG::begin()
{
  pinMode(ledPin, OUTPUT);
  turnLEDOff();
  
  analogReadResolution(12); //12-bits = 0-4095
  
  setLEDCurrent(63); //smallest LED current by default

  ad5242 = AD524X(ad5242_address);
}

//void GammaPPG::turnLEDOn()
//Turns on LED by writing HIGH to pin. LED is driven using an NPN bipolar
//junction transistor (BJT).
void GammaPPG::turnLEDOn()
{
  digitalWrite(ledPin, HIGH);
  ledState = true;
}


//void GammaPPG::turnLEDOff()
//Turns off LED by writing LOW to pin. LED is driven using an NPN bipolar
//junction transistor (BJT).
void GammaPPG::turnLEDOff()
{
  digitalWrite(ledPin, LOW);
  ledState = false;
}


//bool GammaPPG::getLEDStatus() const
//Returns whether or not the LED is on (true) or off (false).
bool GammaPPG::getLEDStatus() const
{
  return ledState;
}


//void GammaPPG::setLEDCurrent(uint8_t val)
//val   value to write to AD5171. Must be between 0 and 63.
//
//Code Reference: https://www.arduino.cc/en/Tutorial/DigitalPotentiometer
//
//This function writes to the digital potentiometer (AD5171 in this version)
//that controls the brightness of the LED.
//
//Current into the LED is determined by the following equations:
//    I_B = (3.3V-0.6V)/(R_pot + R16)
//    LED_current = I_B*Gain
//    Current gain of an NPN transistor is
//    often written as HFE in datasheets
//
//"val" has an inverse relationship with LED current
//As val goes up, resistacee goes up, LED current goes down
//As val goes down, resistacee goes down, LED current goes up
void GammaPPG::setLEDCurrent(uint8_t val)
{
  //val = val*(!(val/63)) + 63*(!(!(val/63)));
  if(val > 63) 
  {
    val = 63;
  }
  Wire.beginTransmission(ad5171_address); //address is specified in datasheet
  Wire.write(byte(0x00)); // sends instruction byte
  Wire.write(val); // sends potentiometer value byte (between 0 and 63)
  Wire.endTransmission(); // stop transmitting
  R_ledCurrent = val;
}

//uint8_t GammaPPG::getLEDCurrent() const
//
//Returns the setting of the digital potentiometer controlling the LED current.
uint8_t GammaPPG::getLEDCurrent() const
{
  return R_ledCurrent;
}


//void GammaPPG::balanceLEDCurrent()
//
//Balances the LED brightness with the TIA gain. Sets the TIA gain to a nominal
//value given the TIA maximum range. Setting the digital potentiomter (AD5242)
//to decimal = 17, gives a resistance of 67 kiloOhms. By doing so, the TIA gain
//can be moduled in at least one order of magnitude in either direction,
//smaller (6.7 kiloOhms) or larger (667 kiloOhms).
//
//Then proceeds to adjust the LED brightness around this nominal TIA gain.
void GammaPPG::balanceLEDCurrent()
{
  //set to some nominal value
  setTIAGain(17);
  //add a bit of delay for settling time;
  delay(1);
  //measure TIA output voltage
  uint16_t Vtia = getTIA();
  //the bounds are about 10% of 1/2 of full ADC scale
  //adjust the LED current so the TIA fits these bounds
  while(Vtia > 2250 || Vtia < 1850)
  {
    //if LED is too bright (voltage output of the
    //TIA is too large, then decrease LED brightness
    if(Vtia > 2250 && R_ledCurrent > 0) setLEDCurrent(R_ledCurrent-1);
    
    //if LED is too dim (voltage output of the
    //TIA is too small, then increase LED brightness
    else if(Vtia < 1850 && R_ledCurrent < 63) setLEDCurrent(R_ledCurrent+1);
    
    //if I'm already at the minimum or maximum of the LED current, then
    //I need to adjust the TIA gain instead
    else balanceTIAGain();
    
    //add a bit of delay for settling time;
    delay(1);
    
    //check the TIA voltage again
    Vtia = getTIA();
  }
}


//void GammaPPG::setTIAGain(uint8_t gain)
//gain      value between 0-255 to set resistance of digital potentiometer
//
//Sets gain of digital potentiometer connected to transimpedance amplifier.
//As gain increases, resistance of potentiometer increases, gain of TIA
//increases, output voltage increases.
void GammaPPG::setTIAGain(uint8_t gain)
{
  ad5242.write(0,gain);
  R_tiaGain = gain;
}


//uint8_t GammaPPG::getTIAGain() const
//
//Returns gain setting of digital potentiometer connected to TIA
uint8_t GammaPPG::getTIAGain() const
{
  return R_tiaGain;
}


//void GammaPPG::balanceTIAGain()
//
//Balances the TIA gain with the LED gain. Sets the TIA gain to 1/2 full
//ADC. Since the PPG circuit has a "virtual ground" at 1/2 full ADC,
//setting the output of the TIA gives the PPG circuit the lowest settling
//time and highest responsivity.
void GammaPPG::balanceTIAGain()
{
  //measure TIA output voltage
  uint16_t Vtia = getTIA();
  
  while(Vtia > 2250 || Vtia < 1850)
  {
    //if voltage output of TIA is too large, then decrease TIA gain
    if(Vtia > 2250 && R_tiaGain > 0) setTIAGain(R_tiaGain-1);
    
    //if voltage output of TIA is too small, then increase TIA gain
    else if(Vtia < 1850 && R_tiaGain < 255) setTIAGain(R_tiaGain+1);
    
    //if R_tiaGain parameter is already at its maximum (255)
    //or minimum (0), then adjust the LED current instead.
    else balanceLEDCurrent();
    
    delay(1); //add a bit of delay for settling time;
    
    Vtia = getTIA();
  }
}

//uint16_t GammaPPG::getTIA() const
//
//Reads voltage of transimpedance amplifier
uint16_t GammaPPG::getTIA() const
{
  return analogRead(tiaPin);
}


//void GammaPPG::setPPGGain(uint8_t gain)
//gain      value between 0-255 to set resistance of digital potentiometer
//
//Sets gain of digital potentiometer connected to bandpass filter.
//As gain parameter increases, resistance of potentiometer increases, gain of
//bandpass filter increases, output voltage increases.
void GammaPPG::setPPGGain(uint8_t gain)
{
  ad5242.write(1,gain);
  R_ppgGain = gain;
}

//uint8_t GammaPPG::getPPGGain() const
//Returns gain setting of digital potentiometer connected to bandpass filter
uint8_t GammaPPG::getPPGGain() const
{
  return R_ppgGain;
}
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

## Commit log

2020-06-04 Completed Organization of Smartwatch Repository
    [Gamma-BOTTOM-BOM.xlsx, Gamma-BOTTOM.brd, Gamma-BOTTOM.sch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]
2020-06-04 First update to the Top board
    [Gamma-TOP.brd, Gamma-TOP.sch]
2020-06-05 Fixed an overlap of two components
    [Gamma-TOP.brd]
2020-06-11 Update to Top and Bottom Boards. Top is not complete as of yet, and the bottom is ready for a check. Routing not performed yet
    [Gamma-BOTTOM.brd, Gamma-BOTTOM.sch, Gamma-TOP.brd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]
2020-06-28 Finished Bottom Board as of Take 003
    [Gamma-BOTTOM.brd, Gamma-BOTTOM.sch]
2020-07-01 Finished Take 004 up until deletion of NFC capacitors. Board partially routed
    [Gamma-TOP.brd, Gamma-TOP.sch]
2020-07-02 This is the routing as of Take 006 before the removal of the SD Card
    [Gamma-TOP.brd, Gamma-TOP.sch]
2020-07-02 Partway through Take 007
    [Gamma-TOP.brd, Gamma-TOP.sch]
2020-07-02 Pushed Changes to where I'm at (Take 007)
    [Gamma-BOTTOM.brd, Gamma-BOTTOM.sch]
2020-07-03 Take 007 35:16, before I attempt to move the power circuit on bottom of Top board out to the outside regions
    [Gamma-TOP.brd, Gamma-TOP.sch]
2020-07-03 Finished with Preliminary Version A of Smartwatch as of end of Take 008 video
    [Gamma-BOTTOM.brd, Gamma-BOTTOM.sch, Gamma-TOP.brd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]
2020-07-04 First stage of prototyping
2020-07-04 Updated file structure
    [Gamma-TOP.brd]
2020-07-08 Updated PPG module BOM and board/schematic. Note: the board and schematic were taken directly from the Kick Jr repository without modification
    [Gamma-PPG-MODULE-BOM.xlsx, Gamma-PPG-Module.brd, Gamma-PPG-Module.sch]
2020-08-17 Changes including: Creation of final board designs, firmware updates, creation of NFC antenna device in Eagle
    [Gamma-BOTTOM-Version2.brd, Gamma-BOTTOM-Version2.sch, Gamma-PPG-MODULE-BOM.xlsx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]
2020-08-17 Updated file names and completed preliminary BOM for each board
    [Gamma-BOTTOM-BOM.xlsx, Gamma-BOTTOM-OLD.brd, Gamma-BOTTOM-OLD.sch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]
2020-08-24 Fixed organization of Smartwatch old and new files
    [Gamma-TOP.brd, Gamma-TOP.sch]
2020-10-28 small fixes
    [Gamma-BOTTOM-OLD.brd, Gamma-BOTTOM.brd, Gamma-TOP.brd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]
